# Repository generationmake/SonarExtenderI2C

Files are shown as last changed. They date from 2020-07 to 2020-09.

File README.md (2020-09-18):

# SonarExtenderI2C
Connect up to four Ultrasonic sensor HC-SR04 via I2C to an Arduino or Raspberry Pi

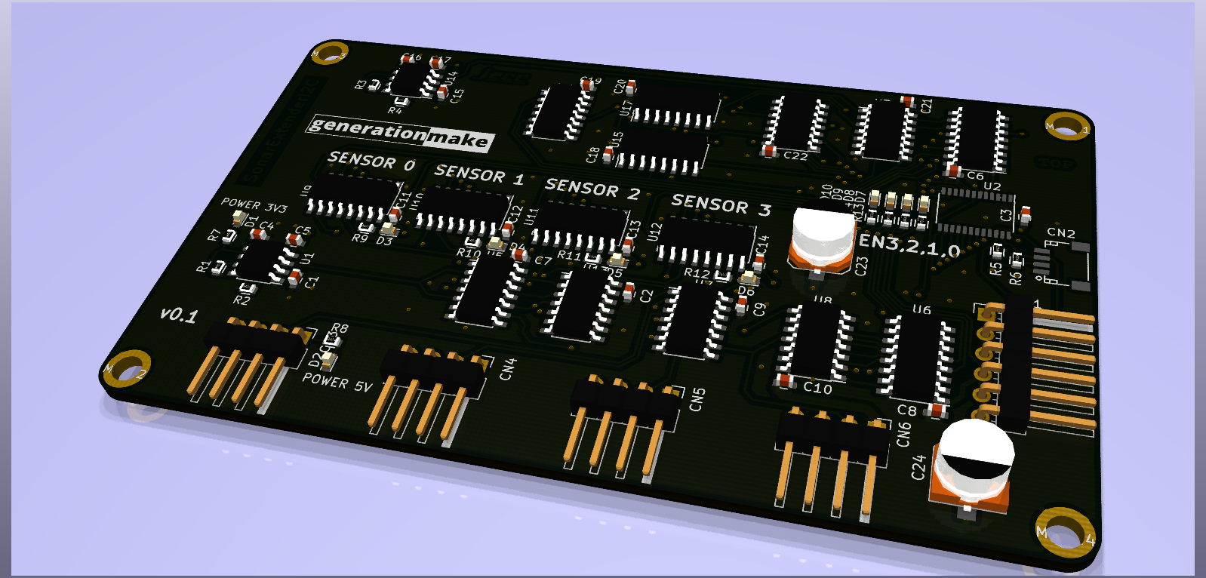
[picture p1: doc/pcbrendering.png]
SonarExtender rendering


## Connection

### Ultrasonic sensor connection (CN3-CN6)

| Pin | Function |
|-----|---|
| 1 | 5V |
| 2 | Trigger |
| 3 | Echo |
| 4 | GND |

### Mikrocontroller connection (P1)

| Pin | Function |
|-----|---|
| 1 | GND |
| 2 | SCL |
| 3 | SDA |
| 4 | Logic voltage (3V3/ 5V) |
| 5 | Interrupt pin |
| 6 | Ultrasonic sensor voltage (5V) |

## How to use

The sensorboard is based on the 16-bit I2C Expander TCA9535 with the slave address 0x20. There are two operating modes for the device. In the manual mode You can evaluate every sensor on Your own, in the automatic mode, all four sensors are evaluated sequentially and an interrupt is rising when all four sensors are triggered once.

### TCA9535 pinout

| Pin | Function |
|-----|---|
| P0 | DECODE0 |
| P1 | DECODE1 |
| P2 | DECODE2 |
| P3 | STATUS ECHO |
| P4 | TRIGGER0 |
| P5 | TRIGGER1 |
| P6 | TRIGGER2 |
| P7 | TRIGGER3 |
| P10 | D0 |
| P11 | D1 |
| P12 | D2 |
| P13 | D3 |
| P14 | D4 |
| P15 | D5 |
| P16 | D6 |
| P17 | D7 |

### Manual mode

#### 1. Initiate trigger signal 

Before every manual measurement make sure, that TRIGGER0-TRIGGER3 are low and DECODE0-DECODE2 are smaller than 4 in binary.
In manual mode You can trigger a sensor by setting TRIGGER0-TRIGGER3 high according to which sensors You want to use:

| | TRIGGER0 | TRIGGER1 | TRIGGER2 | TRIGGER3 |
|---|----|----|----|----|
| Sensor 0 | H | L | L | L |
| Sensor 1 | L | H | L | L |
| Sensor 2 | L | L | H | L |
| Sensor 3 | L | L | L | H |

#### 2. Wait for measurements to finish

If all measurements are finished STATUS ECHO will go high. Here it is important to wait a minimum of 100ms after triggering the sensor.

#### 3. Evaluate the measurement result

The sensorboard has a 8-bit counter for every sensor, that is started and stopped automatically according to the measurement cycles. You can read the data on D0-D7 by setting DECODE0-DECODE2 to the right counter:

| | DECODE0 | DECODE1 | DECODE2 |
|---|----|----|----|
| Sensor 0 | L | L | L |
| Sensor 1 | H | L | L |
| Sensor 2 | L | H | L |
| Sensor 3 | H | H | L |

As the counters are running at a 10kHz frequency and the ultrasonic signal needs 29.4us to travel one centimeter, You can calculate the distance to an object in cm by the following formular: ```distance = 100*countervalue/2/29.4```. The maximum distance is 425cm with an accuracy of 4.25cm.

### Automatic mode

#### Starting and stopping the automatic mode

To start the automatic mode, the DECODE Pins need to be set to binary 4, in any other configuration it will not run.
Then all sensors will be triggered one after another.

#### Evaluating the automatic mode results

If all sensors are triggered, the interrupt pin wil rise and You can evaluate the results like in section 2.) of the manual mode.

#### Pausing the automatic mode

To pause the automatic mode, simply set the DECODE Pins to binary 5. In opposite to binary 4, it won't reset and continue with the next sensor.

## Arduino lib

https://github.com/wuehr1999/SonarExtenderI2C-Library

## Aisler order link

https://aisler.net/jonaswuehr/sandbox/sonar-extender-i2-c

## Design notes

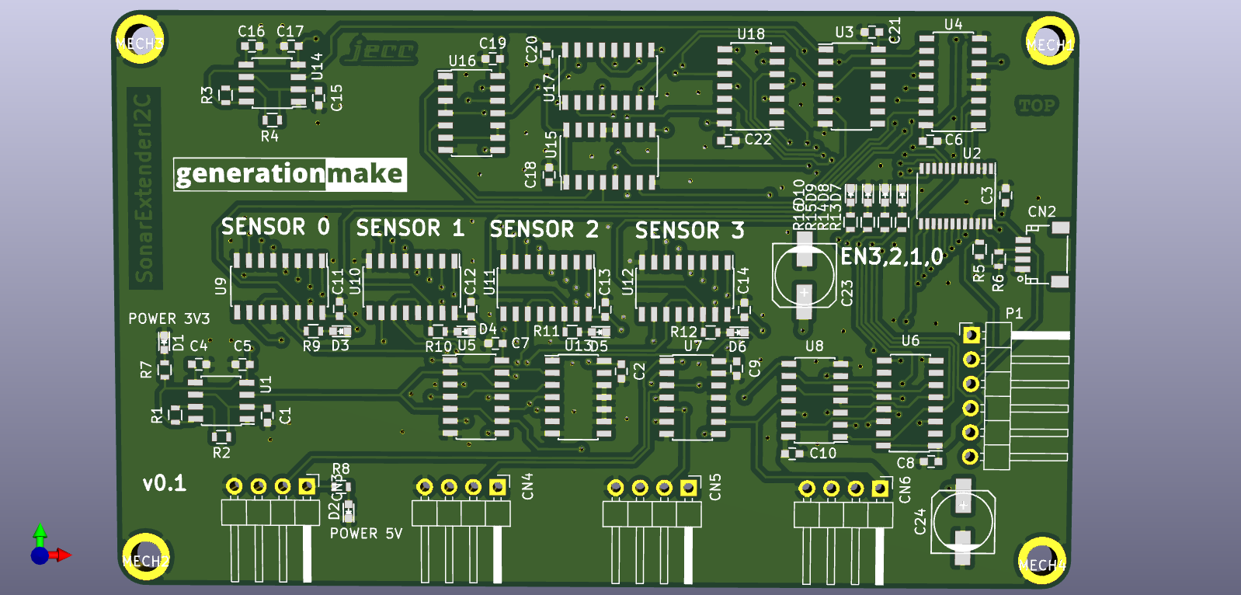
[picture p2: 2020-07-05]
doc/toplayer.png

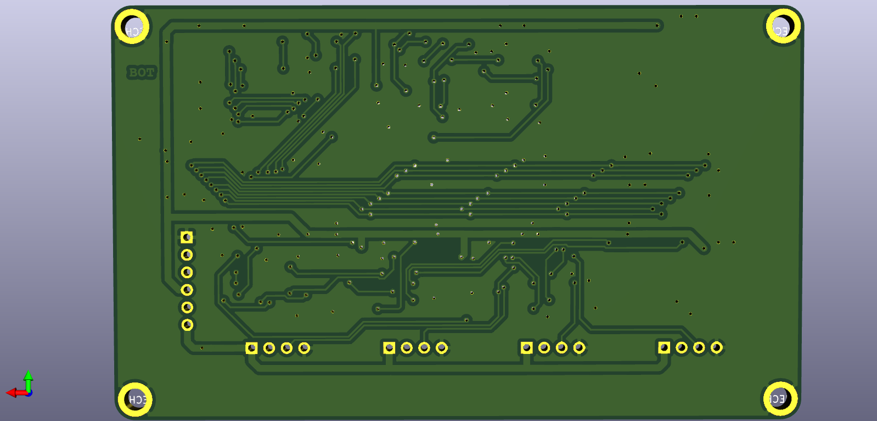
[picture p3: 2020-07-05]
doc/bottomlayer.png

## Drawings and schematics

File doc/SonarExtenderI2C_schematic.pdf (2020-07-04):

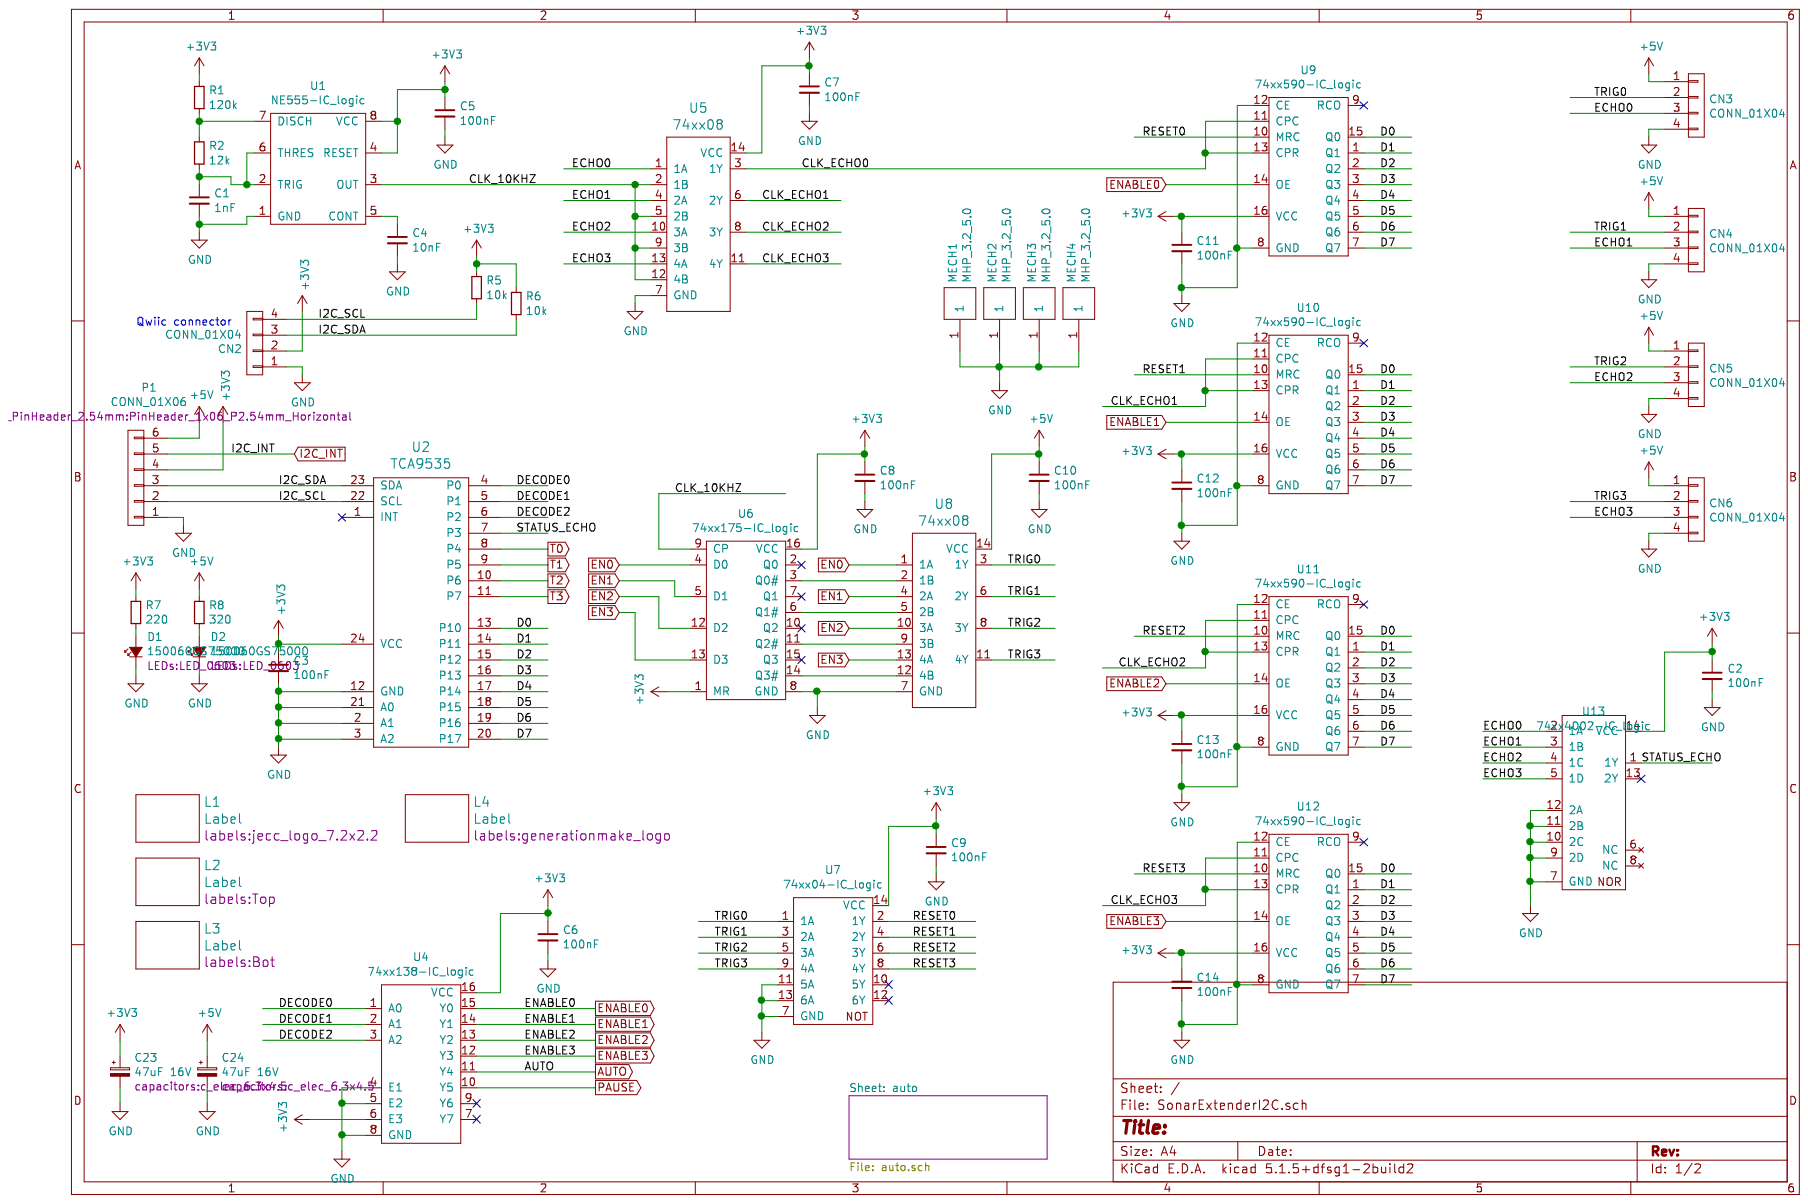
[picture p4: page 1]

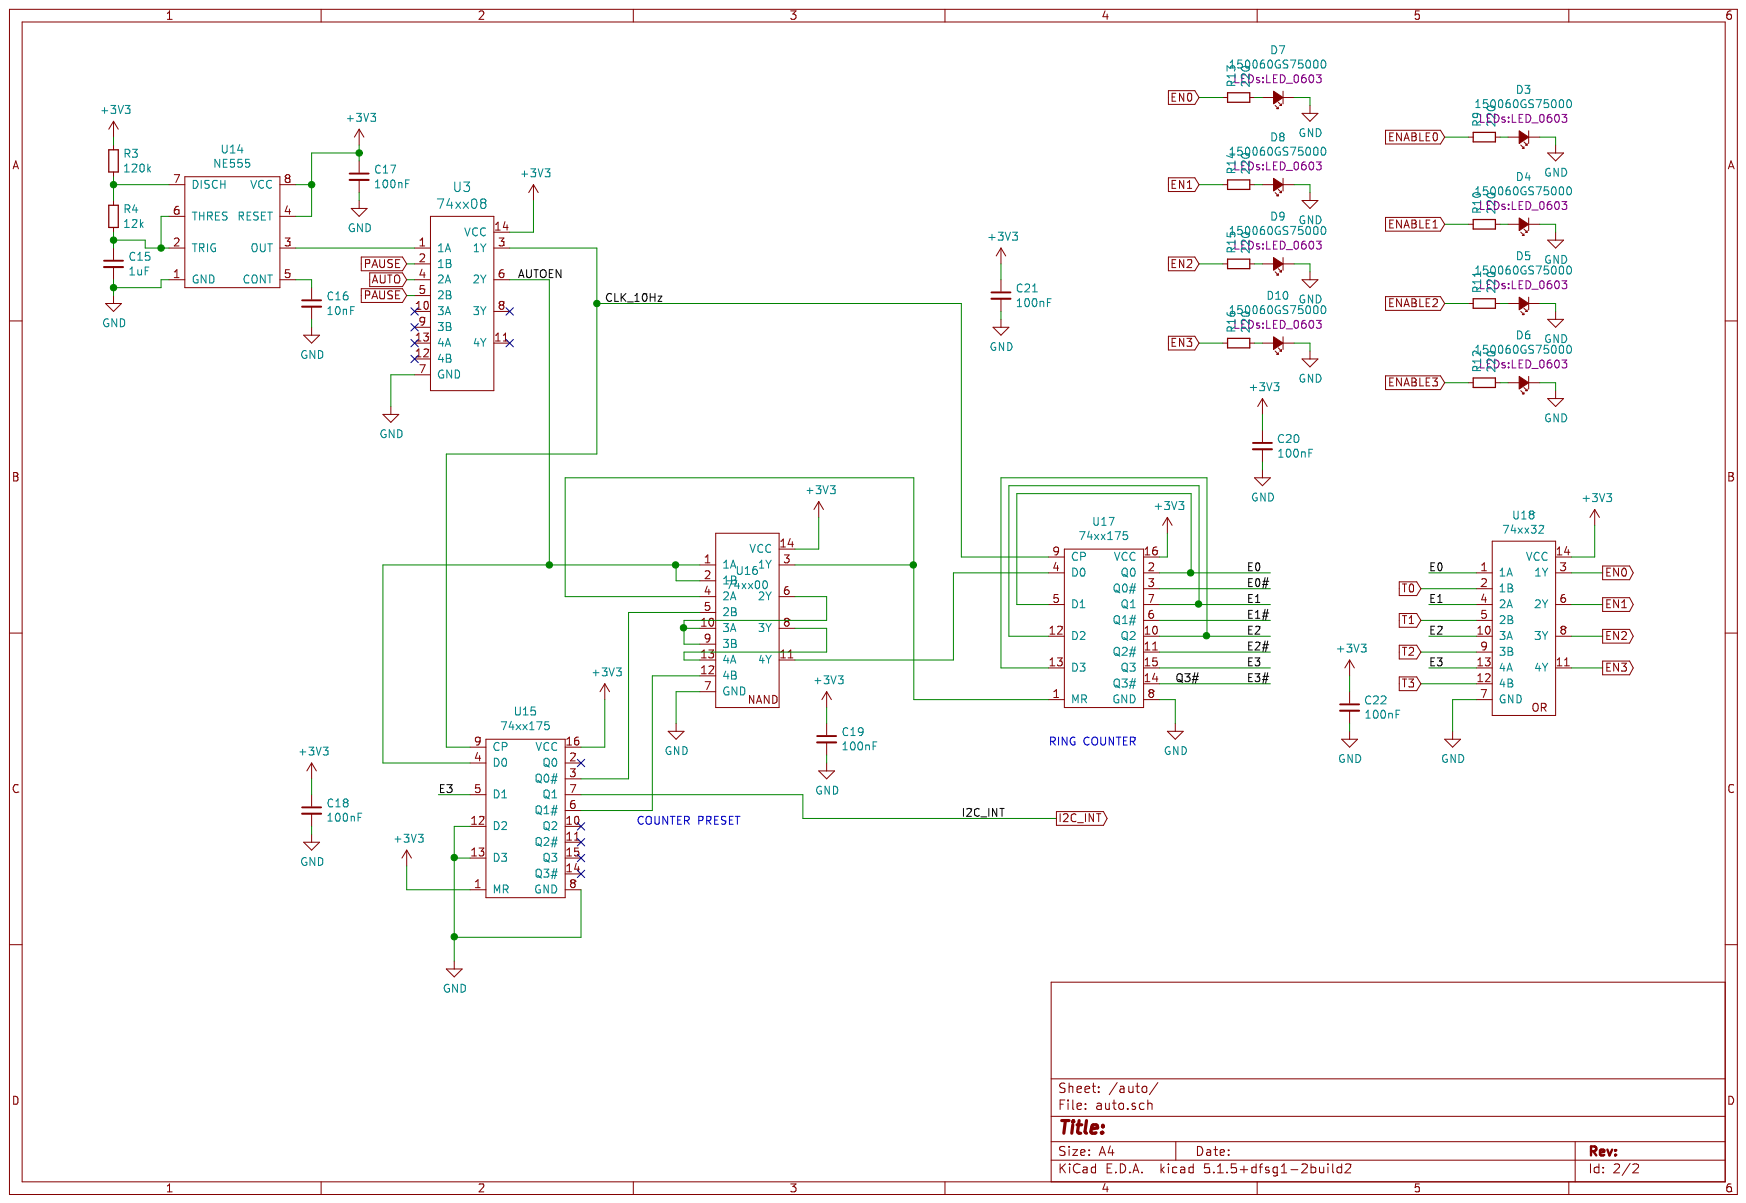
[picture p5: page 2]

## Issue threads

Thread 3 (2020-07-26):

Pin out in silkscreen

generationmake, 2020-07-26:
add pin out of P1 and CN3..CN5 in silkscreen of PCB to allow easier conection with Arduino.

wuehr1999, 2020-09-17:
https://github.com/generationmake/SonarExtenderI2C/pull/7

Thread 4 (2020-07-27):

reduce intensity of LEDs

generationmake, 2020-07-27:
change LED resistor to 1k ohm or higher value.

Better for programming late at night.

generationmake, 2020-07-27:
should also reduce power consumption

wuehr1999, 2020-09-17:
https://github.com/generationmake/SonarExtenderI2C/pull/7

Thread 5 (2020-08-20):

more possible I2C addresses

generationmake, 2020-08-20:
connect the address lines of the I2C device to resistors so that different I2C addresses of the board are possible and more boards can beplaced on the same I2C bus.

wuehr1999, 2020-09-17:
https://github.com/generationmake/SonarExtenderI2C/pull/7

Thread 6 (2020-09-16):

Simplify autonomous evaluation

wuehr1999, 2020-09-16:
The autonomous evalutation could  be also realized more simple and reliable with a counter and BCD encoder. This concerns especially the chance of pausing the auto triggering sequence.

wuehr1999, 2020-09-17:
https://github.com/generationmake/SonarExtenderI2C/pull/7

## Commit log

2020-06-01 added first draft of schematic
    [SonarExtenderI2C.kicad_pcb, SonarExtenderI2C.sch]
2020-06-01 added auto measure circuit and echo status
    [SonarExtenderI2C.sch, auto.sch]
2020-06-01 added ground/ 3v3 connections
    [auto.sch]
2020-06-01 added logic table for auto evaluation
    [logicautoevaluate.ods]
2020-06-01 changed and colorized logic table
    [SonarExtenderI2C.sch, auto.sch, logicautoevaluate.ods]
2020-06-01 colorized logic table
    [logicautoevaluate.ods]
2020-06-01 centered logic table
    [logicautoevaluate.ods]
2020-06-02 changed logic table
    [logicautoevaluate.ods]
2020-06-07 added connector for I2C, annotated schematic
    [SonarExtenderI2C.sch, auto.sch]
2020-06-07 assigned footprints to all parts, generated netlist
2020-06-07 exchanged I2C expanders to TCA9535 (16 bit type), generated schematic pdf
    [SonarExtenderI2C.sch, auto.sch]
2020-06-08 schematic changed
    [SonarExtenderI2C.sch, auto.sch]
2020-06-10 finished pcb layout
    [SonarExtenderI2C.kicad_pcb, SonarExtenderI2C.sch, auto.sch]
2020-06-13 reacted to review
    [SonarExtenderI2C.kicad_pcb, SonarExtenderI2C.sch, auto.sch]
2020-06-15 added led digikey order numbers
    [SonarExtenderI2C.sch, auto.sch]
2020-06-22 updated logic table
    [SonarExtenderI2C.kicad_pcb, logicautoevaluate.ods]
2020-06-28 added pause mode for automate
    [SonarExtenderI2C.kicad_pcb, SonarExtenderI2C.sch, auto.sch]
2020-06-29 layout changed
    [SonarExtenderI2C.kicad_pcb]
2020-07-03 added EN LEDS
    [SonarExtenderI2C.kicad_pcb, auto.sch]
2020-07-04 updated schematics pdf
2020-07-05 moved files
    [logicautoevaluate.ods, logicautomaticmode.ods]
